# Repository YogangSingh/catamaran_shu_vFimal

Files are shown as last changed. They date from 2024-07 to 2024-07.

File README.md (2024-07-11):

# catamaran_shu_v2
 repo for the improved catamaran design

# Catamaran SHU

## Introduction
Catamaran SHU V2 is the improved version of the autonomous surface vehicle built and designed by me for my masters thesis. This version has improved electronics hardware and design changes that make the USV betters
## Features
- Feature 1: BNO055 IMU Integration.
- Feature 2: RTK GPS Added (GPS-RTK2 Board - ZED-F9P ).
- Feature 3: Dual mode control: radio control mode and autonomous mode.
- Feature 4: Arduino <-> ROS Integration on Arduino MEGA 2560..
- Feature 5: 360 Degree Lidar. (RPLidar s2)
  
## Getting Started
These instructions will get you a copy of the project up and running on your local machine for development and testing purposes.

### Prerequisites
What things you need to install the software and how to install them:
```
[Install ROS Noetic]
wget -c https://raw.githubusercontent.com/qboticslabs/ros_install_noetic/master/ros_install_noetic.sh && chmod +x ./ros_install_noetic.sh && ./ros_install_noetic.sh
``
[Install Ubuntu and Ubuntu Desktop on Raspberry Pi]
sudo apt-get update
sudo apt-get install ubuntu-desktop

```

### Installing
A step-by-step series of examples that tell you how to get a development environment running:

1. Clone the repo:
   ```
   git clone https://github.com/broskunta/catamaran_shu_v2.git
   ```
2. Navigate to the project directory:
   ```
   cd catamaran_shu_v2
   ```
3. Run catkin_make
   ```
   catkin_make
   ```
4. Navigate to the src directory:
   ```
   cd catamaran_shu_v2\src
   ```
5. Clone Required Repos
   ```
   git clone https://github.com/tu-darmstadt-ros-pkg/hector_slam
   git clone https://github.com/KumarRobotics/ublox.git
   git clone https://github.com/Slamtec/rplidar_ros
   git clone https://github.com/tilk/rtcm_msgs
   ```

## Usage
How to use the project:
```
1. Make sure the Arduino board with the IMU is connected on /dev/tty/USB0.
2. Make sure the GPS is connected on /dev/ttyACM0 on the RPi.
3. Make sure the Lidar is connected on /dev/ttyUSB1 on the RPi.
4. Run the robot with the usv_control.launch file
```

## Running the Tests
Explain how to run the automated tests for this system:
```
[For Straight Line Behaviour Test]
roslaunch gps_navigation straight_behaviour.launch
```
```
[For Circular Behaviour Test]
roslaunch gps_navigation circular_behaviour.launch 
```

## License
This project is licensed under the MIT License - see the [LICENSE.md](LICENSE.md) file for details.

## Acknowledgments
- Daniel Riley https://www.rctestflight.com/
- The team at Heron USV https://github.com/heron
- https://github.com/bsb808
- The team at TheConstruct. https://www.theconstructsim.com/
- The Technovation Team https://www.instructables.com/member/Technovation/
-  Sidney Okoroafor https://github.com/Syd-E

---

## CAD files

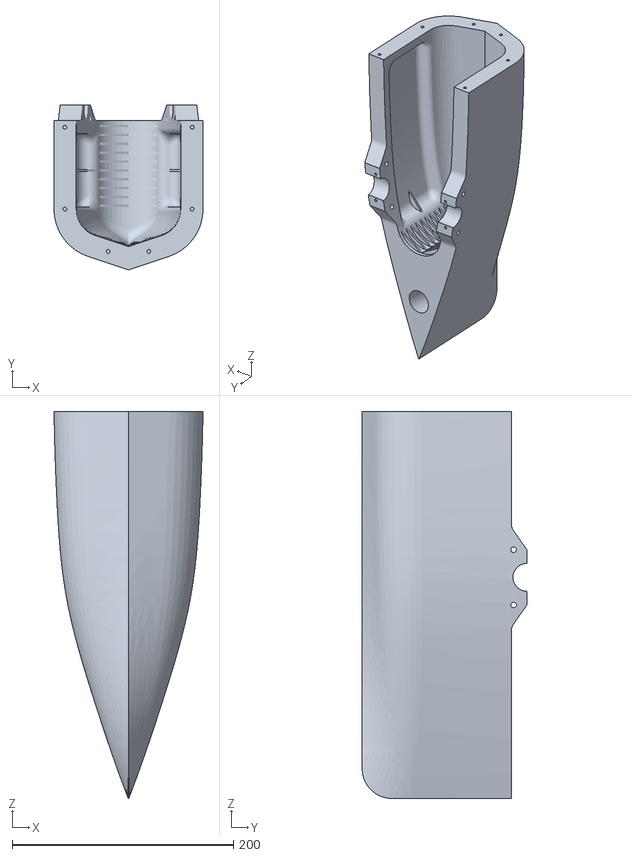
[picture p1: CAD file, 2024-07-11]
CAD Files/Cat Hull.STL
134.7 x 149.0 x 350.0

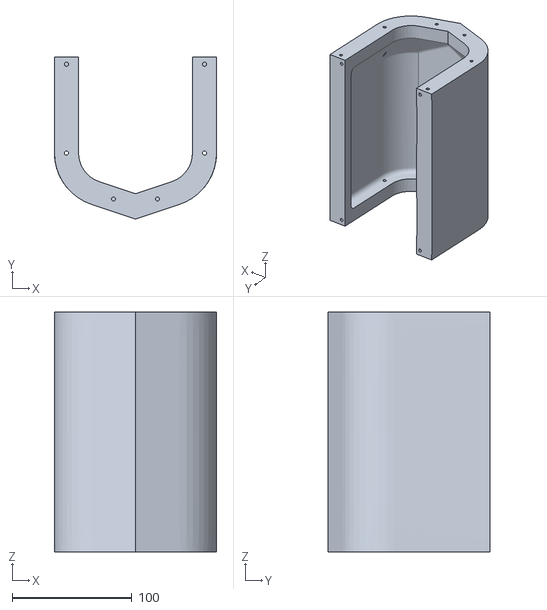
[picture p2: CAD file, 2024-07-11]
CAD Files/Cat Hull Middle.STL
135.3 x 135.0 x 200.0

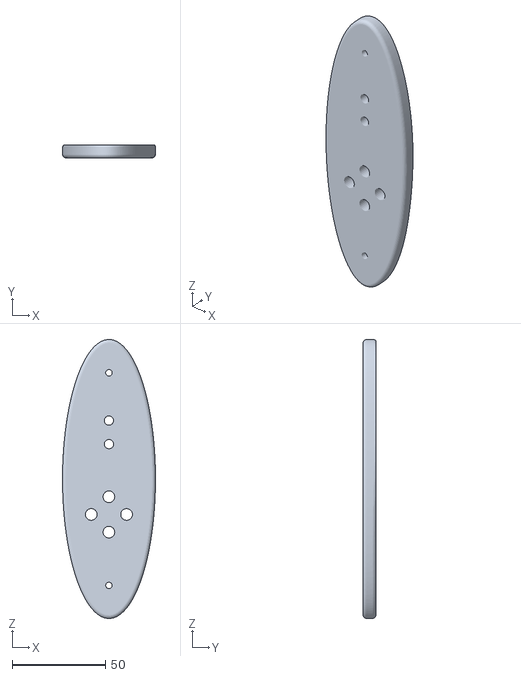
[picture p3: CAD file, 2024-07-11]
CAD Files/Mod-UW_base (Do not scale).stl
50.0 x 7.00 x 150.0

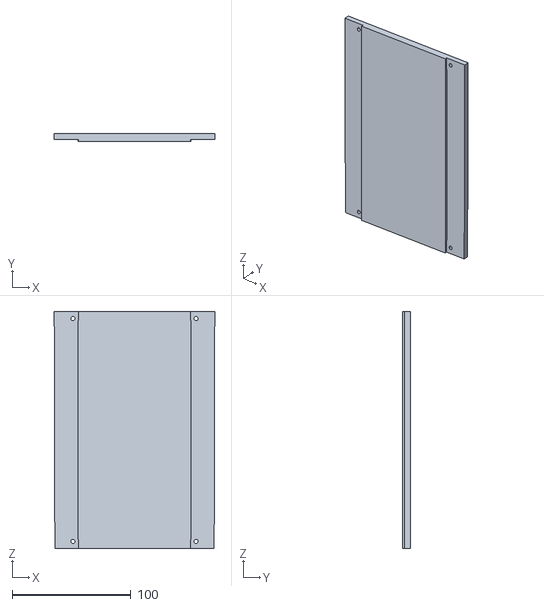
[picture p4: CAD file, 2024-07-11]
CAD Files/Boat middle cover.stl
135.5 x 7.00 x 200.0

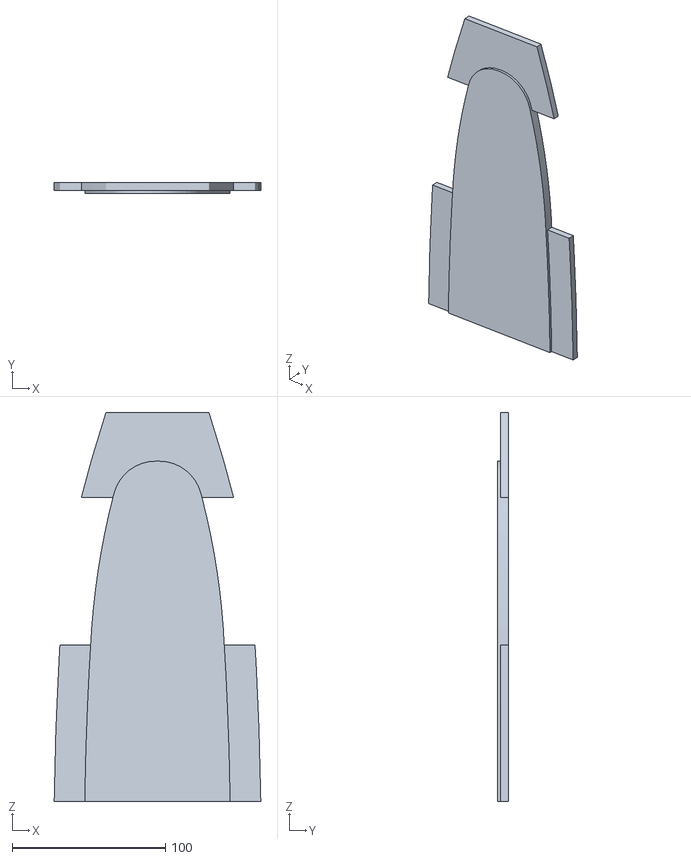
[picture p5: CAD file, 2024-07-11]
CAD Files/Boat cover 3.stl
134.7 x 7.00 x 253.5

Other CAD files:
CAD Files/Boat Front Cover.stl

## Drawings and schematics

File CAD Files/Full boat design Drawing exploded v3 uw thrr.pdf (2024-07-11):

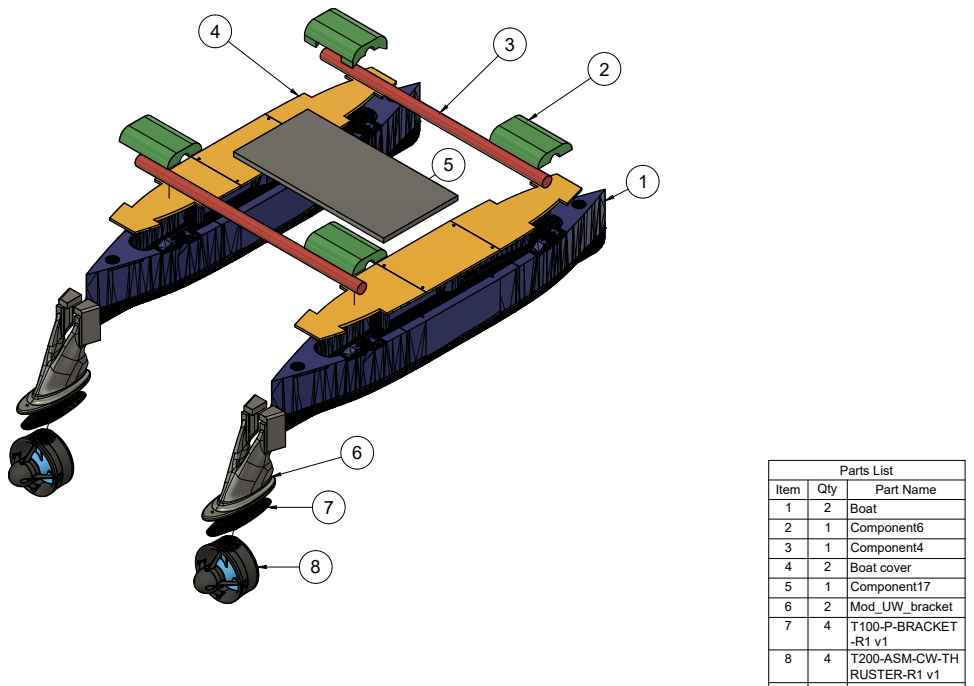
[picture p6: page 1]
Parts List; Item; Qty; Part Name 1; Boat 2; Component6 3; Component4 4; Boat cover 5; Component17 6; Mod_UW_bracket 7; T100-P-BRACKET; T200-ASM-CW-TH; RUSTER-R1 v1 9; Cat Hull v3

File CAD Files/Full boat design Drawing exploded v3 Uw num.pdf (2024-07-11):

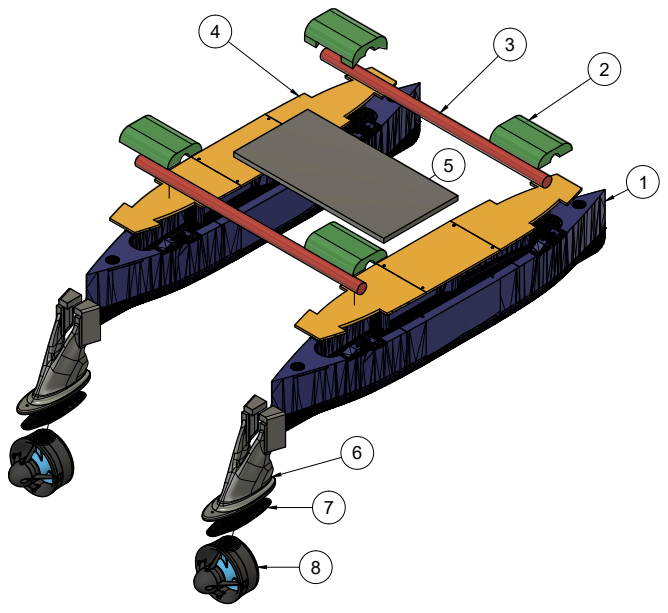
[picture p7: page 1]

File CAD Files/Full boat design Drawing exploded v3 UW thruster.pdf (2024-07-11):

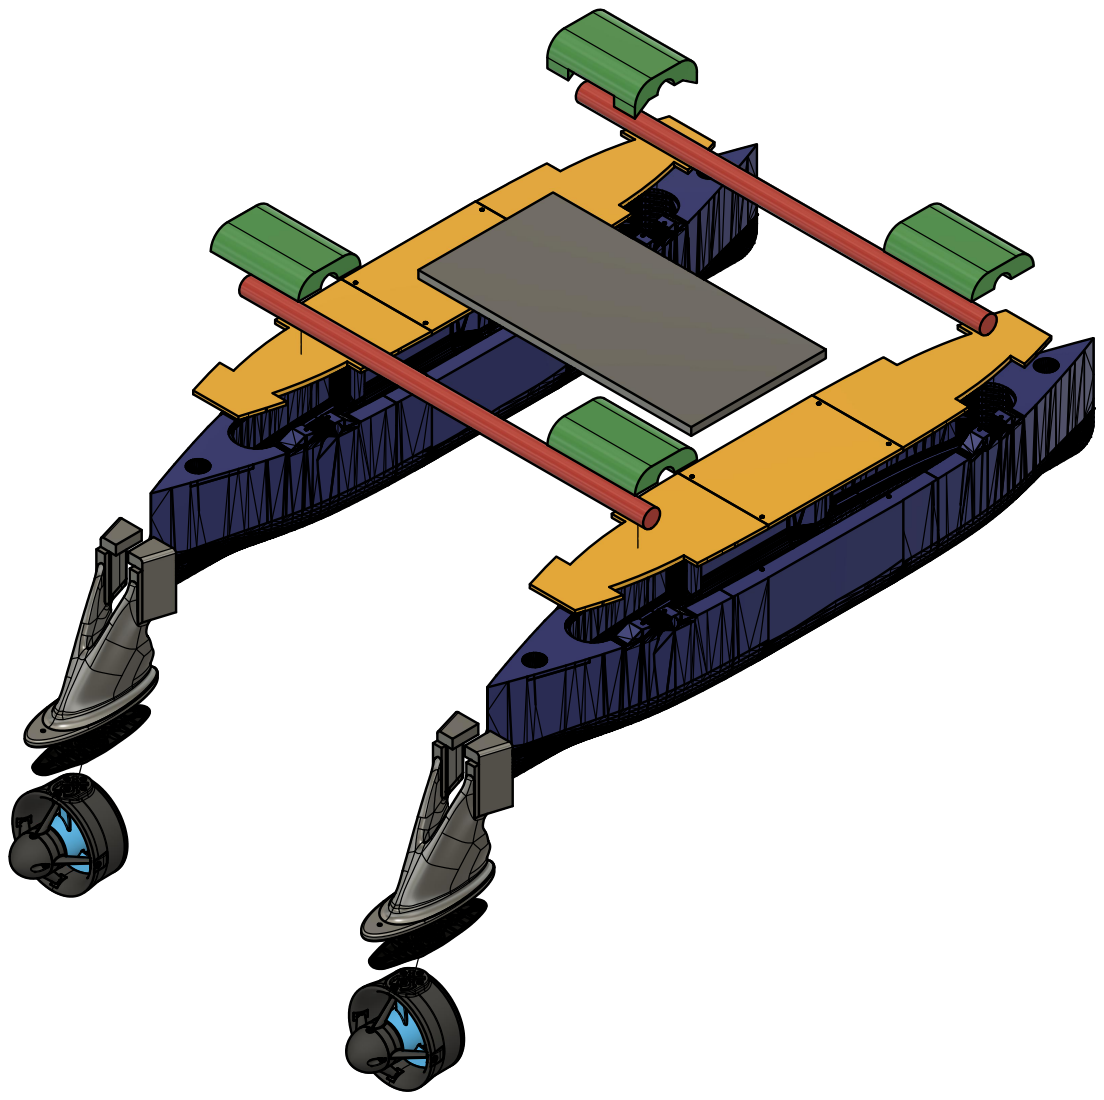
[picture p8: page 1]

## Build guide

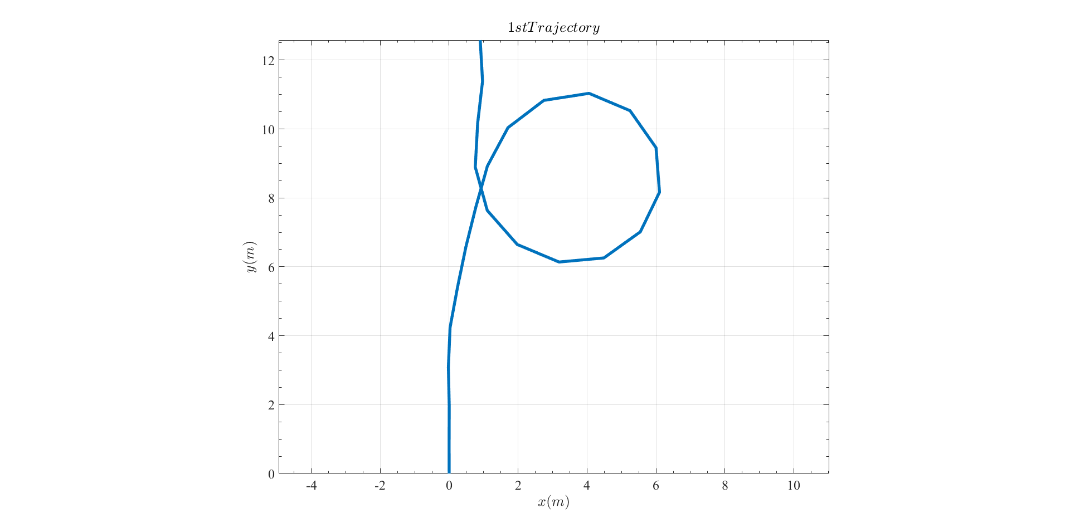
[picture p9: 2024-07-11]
USV2 Test Data/print1.png

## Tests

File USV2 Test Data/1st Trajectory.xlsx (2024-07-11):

X | Y | Xzero | Xpos | Yzero | .latitude | .longitude | /imu.orientation.w | /imu.orientation.x | /imu.orientation.y | /imu.orientation.z | elapsed time | receive time
599734.89 | 5911420.889 | 0 | 0 | 0 | 53.3413995 | -1.502048667 | 0.9506835938 | -0.02178955078 | -0.09460449219 | -0.2946166992 | 0.728779495 | 1716287602.731446062
599735.4683 | 5911420.308 | 0.5783463661 | -0.5783463661 | 0.5814168295 | 53.34139417 | -1.502040167 | 0.9490966797 | -0.02197265625 | -0.07751464844 | -0.3045043945 | 1.511456699 | 1716287603.514123266
599736.2732 | 5911419.508 | 1.383281925 | -1.383281925 | 1.38066116 | 53.34138683 | -1.502028333 | 0.9501342773 | -0.01995849609 | -0.07336425781 | -0.3024902344 | 2.288903725 | 1716287604.291570292
599737.0564 | 5911418.69 | 2.166414513 | -2.166414513 | 2.19891117 | 53.34137933 | -1.502016833 | 0.9447631836 | -0.02349853516 | -0.07092285156 | -0.319152832 | 3.068369249 | 1716287605.071035816
599737.9053 | 5911417.91 | 3.015346033 | -3.015346033 | 2.97868386 | 53.34137217 | -1.502004333 | 0.9591064453 | -0.00927734375 | -0.07989501953 | -0.271484375 | 3.848517702 | 1716287605.851184269
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

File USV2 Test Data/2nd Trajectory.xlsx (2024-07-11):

X | Y | Xzero | Yzero | .latitude | .longitude | /imu.orientation.w | /imu.orientation.x | /imu.orientation.y | /imu.orientation.z | elapsed time | receive time
599729.7333 | 5911415.346 | 0 | 0 | 53.3413506667 | -1.502127833 | 0.6889038086 | -0.05236816406 | -0.04803466797 | -0.7213745117 | 0.27339406 | 1716286998.273825933
599730.1028 | 5911415.725 | 0.3694890541 | 0.3787190001 | 53.3413540000 | -1.502122167 | 0.6795654297 | -0.0712890625 | -0.06744384766 | -0.7270507812 | 1.050185075 | 1716286999.050616948
599730.7109 | 5911416.368 | 0.977647335 | 1.02212236 | 53.3413596667 | -1.502112833 | 0.6727294922 | -0.06237792969 | -0.06005859375 | -0.7348022461 | 1.831201541 | 1716286999.831633414
599731.2326 | 5911416.899 | 1.499370209 | 1.552422171 | 53.3413643333 | -1.502104833 | 0.6684570312 | -0.03161621094 | -0.03106689453 | -0.7424316406 | 2.6101303 | 1716287000.610562173
599731.7215 | 5911417.41 | 1.988193605 | 2.06348349 | 53.3413688333 | -1.502097333 | 0.6654663086 | -0.04870605469 | -0.046875 | -0.743347168 | 3.39286495 | 1716287001.393296823
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

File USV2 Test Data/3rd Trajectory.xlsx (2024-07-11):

X | Y | Xpos | Ypos | Xzero | Yzero | .latitude | .longitude | /imu.orientation.w | /imu.orientation.x | /imu.orientation.y | /imu.orientation.z | elapsed time | receive time
599733.9305 | 5911421.648 | 0 | 0 | 0 | 0 | 53.3414065 | -1.502062833 | 0.866027832 | -0.03125 | -0.06274414062 | -0.4950561523 | 0.155708607 | 1716287119.157944043
599734.526 | 5911422.365 | -0.5955051631 | -0.7173321405 | 0.5955051631 | 0.7173321405 | 53.34141283 | -1.502053667 | 0.8772583008 | -0.02655029297 | -0.06121826172 | -0.4753417969 | 0.9399582740000001 | 1716287119.942193710
599735.0763 | 5911423.119 | -1.145847949 | -1.47081379 | 1.145847949 | 1.47081379 | 53.3414195 | -1.502045167 | 0.884765625 | -0.02655029297 | -0.06457519531 | -0.4607543945 | 1.71588904 | 1716287120.718124476
599735.6691 | 5911423.966 | -1.738630181 | -2.31792788 | 1.738630181 | 2.31792788 | 53.341427 | -1.502036 | 0.885925293 | -0.02709960938 | -0.06402587891 | -0.4585571289 | 2.495964736 | 1716287121.498200172
599736.3059 | 5911424.832 | -2.375407565 | -3.18451339 | 2.375407565 | 3.18451339 | 53.34143467 | -1.502026167 | 0.8879394531 | -0.02990722656 | -0.07354736328 | -0.4530639648 | 3.276257084 | 1716287122.278492520
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

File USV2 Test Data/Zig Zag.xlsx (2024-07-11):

X | Y | Xpos | Ypos | Xzero | Yzero | .latitude | .longitude | /imu.orientation.w | /imu.orientation.x | /imu.orientation.y | /imu.orientation.z | elapsed time | receive time
599744.1458 | 5911419.414 | 0 | 0 | 0 | 0 | 53.3413845 | -1.501910167 | 0.9755249023 | -0.02001953125 | -0.08563232422 | -0.2015380859 | 0.063026459 | 1716287800.064211793
599744.5885 | 5911418.422 | -0.442655905 | 0.9923276799 | 0.442655905 | -0.9923276799 | 53.3413755 | -1.501903833 | 0.9337768555 | -0.04223632812 | -0.08905029297 | -0.3439331055 | 0.8399374 | 1716287800.841122734
599744.657 | 5911417.273 | -0.511156555 | 2.14089241 | 0.511156555 | -2.14089241 | 53.34136517 | -1.501903167 | 0.8807983398 | -0.05523681641 | -0.07745361328 | -0.4638061523 | 1.621337312 | 1716287801.622522646
599744.37 | 5911416.136 | -0.224193134 | 3.27836629 | 0.224193134 | -3.27836629 | 53.341355 | -1.501907833 | 0.8164672852 | -0.06213378906 | -0.06872558594 | -0.5699462891 | 2.39909612 | 1716287802.400281454
599743.7474 | 5911415.121 | 0.398376218 | 4.293042149 | -0.398376218 | -4.293042149 | 53.341346 | -1.5019175 | 0.742980957 | -0.06994628906 | -0.06622314453 | -0.6622924805 | 3.18188167 | 1716287803.183067004
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

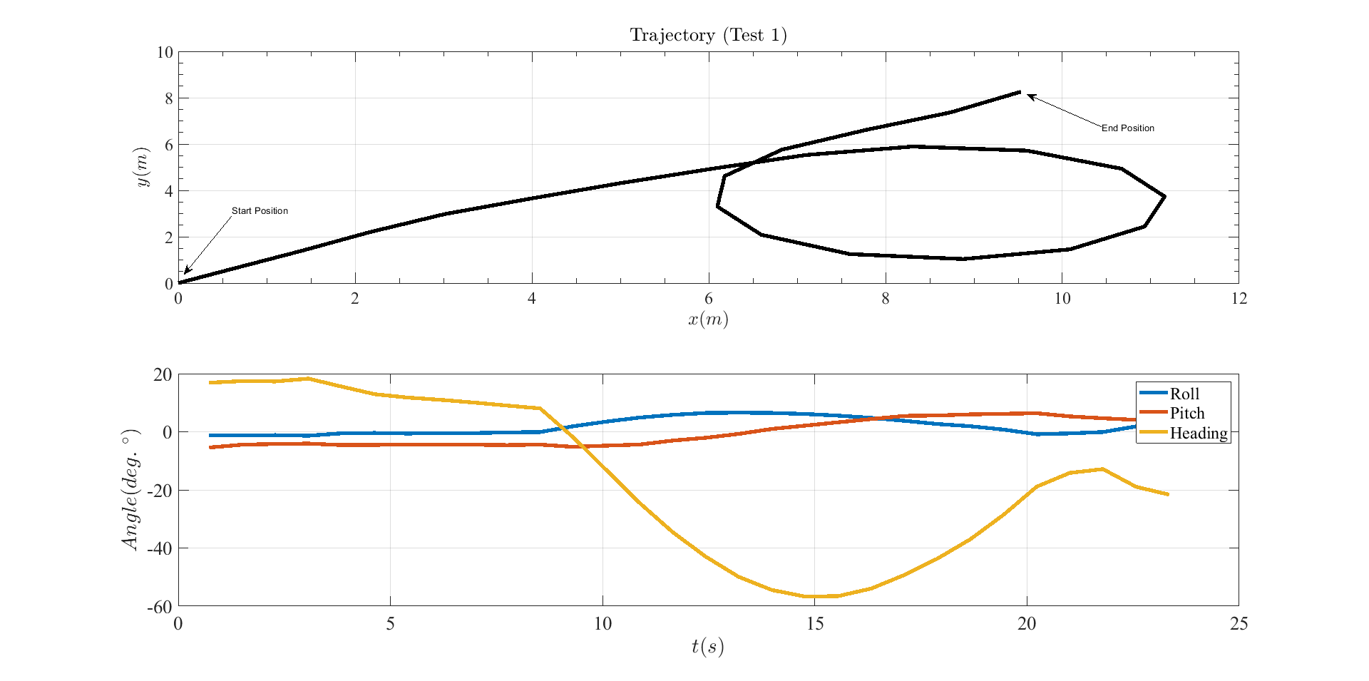
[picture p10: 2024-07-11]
USV2 Test Data/Test 1.png

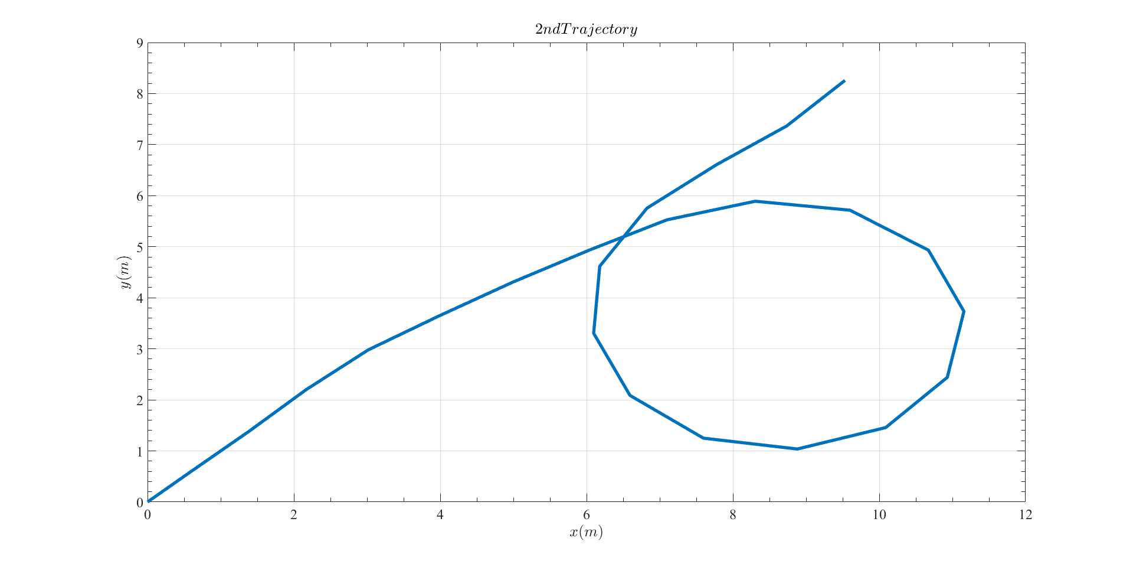
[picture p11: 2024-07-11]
USV2 Test Data/untitled.png

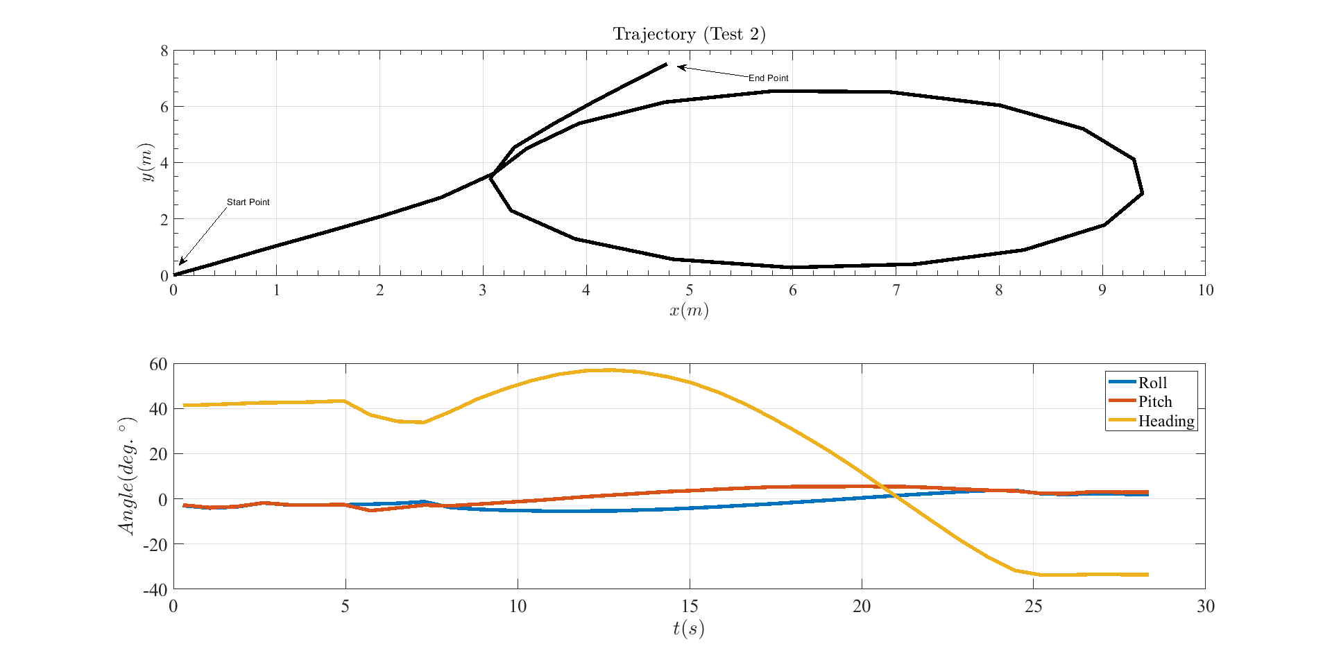
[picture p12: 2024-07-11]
USV2 Test Data/Test 22.png

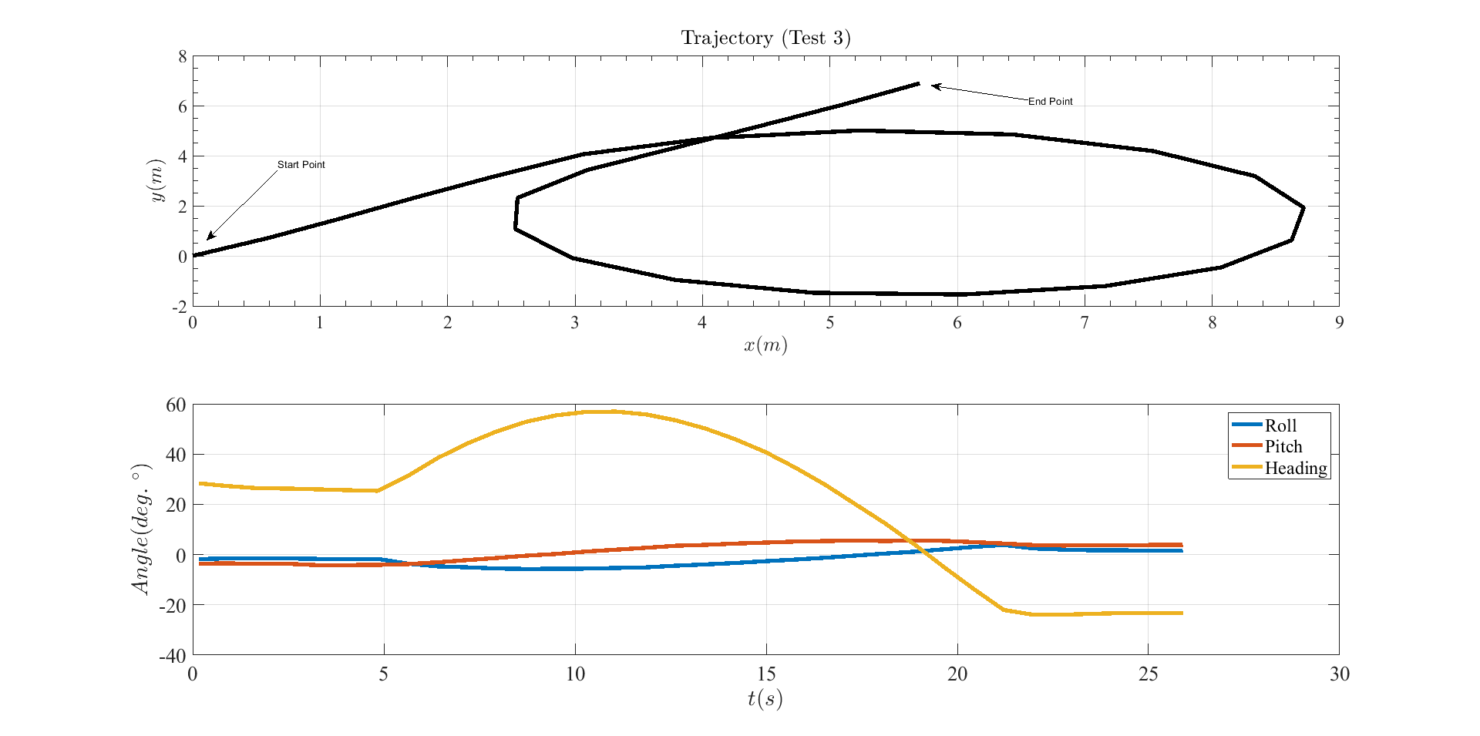
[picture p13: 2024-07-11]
USV2 Test Data/untitled13port.png

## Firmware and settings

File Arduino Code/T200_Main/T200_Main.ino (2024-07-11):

//IMU Code to send IMY data to the IMu part to ROS
//I will need angular velocity, linear acceleration,
//Orientation in quat from the IMU sensor to make this
//code work

//Working code is from ros-robot-programming-book-by turtlebot3-Developers

//ROS Libraries
#include <ros.h>
#include <nav_msgs/Path.h>
#include <sensor_msgs/Imu.h>
#include <tf/tf.h>
#include <tf/transform_broadcaster.h>
#include <geometry_msgs/Twist.h>

//include libraries for Transmitter
#include <SPI.h>
#include <Servo.h>
#include <IBusBM.h>
/*
 *    Connections
   =======================
   IMU
   =======================
   Connect SCL to SCL pin (analog 5 on Arduino UNO)
   Connect SDA to SDA pin (analog 4 on Arduino UNO)
   Connect VDD to 3-5V DC (depending on your board's logic level)
   Connect GROUND to common ground

  =======================
   GPS
  =======================


  =======================
   TRANSMITTER
  =======================


  =======================
   ESCs
  =======================

  =======================
   BOARD RADIO COMMS
  =======================
 * 
 */

// Other arduino libraries
#include <Wire.h>
#include <Adafruit_Sensor.h>
#include <Adafruit_BNO055.h>
#include <utility/imumaths.h>

//Start ROS Handle
ros::NodeHandle nh;

const int MAX_PATH_SIZE = 10;

sensor_msgs::Imu imu_msg;

ros::Publisher imu_pub("imu", &imu_msg);

geometry_msgs::TransformStamped tfs_msg;
tf::TransformBroadcaster tfbroadcaster;

/* Set the delay between fresh samples */
#define BNO055_SAMPLERATE_DELAY_MS (100)

/* Define BNO055 Object */
Adafruit_BNO055 bno = Adafruit_BNO055(55, 0x28, &Wire);

//define comms pins for transmitter
#define RUDDER_PIN 5
#define THROTTLE_PIN 6
#define MODE_PIN 7

//define ESCs pin
Servo left_esc; //left motor
Servo right_esc; //right motor

int left_motor_speed = 1500;
int right_motor_speed = 1500;

// // Read the number of a given channel and convert to the range provided.
// // If the channel is off, return the default value
int readChannel(int channelInput, int minLimit, int maxLimit, int defaultValue){
  int ch = pulseIn(channelInput, HIGH, 30000);
  if (ch < 100) return defaultValue;
  return map(ch, 1000, 2000, minLimit, maxLimit);
}

// Red the channel and return a boolean value
bool redSwitch(byte channelInput, bool defaultValue){
  int intDefaultValue = (defaultValue)? 100: 0;
  int ch = readChannel(channelInput, 0, 100, intDefaultValue);
  return (ch > 50);
}

// Callback functions for the path topics
void generatedPathCallback(const nav_msgs::Path& msg) {
    // Process and print data for /straight_line_behavior_generated_path
    Serial.println("Generated Path Data:");
    for (int i = 0; i < MAX_PATH_SIZE; ++i) {
        // Assuming a pose of all zeros is not valid and indicates the end of the array
        if (msg.poses[i].pose.position.x != 0 || msg.poses[i].pose.position.y != 0 || msg.poses[i].pose.position.z != 0) {
            Serial.print(msg.poses[i].pose.position.x);
            Serial.print(",");
            Serial.print(msg.poses[i].pose.position.y);
            Serial.print(",");
            Serial.print(msg.poses[i].pose.position.z);
            Serial.print("\n");
        } else {
            // Break the loop if the pose is not valid
            break;
        }
    }
}

void followedPathCallback(const nav_msgs::Path& msg) {
    // Process and print data for /straight_line_behavior_followed_path
    Serial.println("Followed Path Data:");
    for (int i = 0; i < MAX_PATH_SIZE; ++i) {
        if (msg.poses[i].pose.position.x != 0 || msg.poses[i].pose.position.y != 0 || msg.poses[i].pose.position.z != 0) {
            Serial.print(msg.poses[i].pose.position.x);
            Serial.print(",");
            Serial.print(msg.poses[i].pose.position.y);
            Serial.print(",");
            Serial.print(msg.poses[i].pose.position.z);
            Serial.print("\n");
        } else {
            break;
        }
    }
}



//wheel data
float wheel_radius = 0.1015; // meters
float wheel_separation = 0.31; // meters
int micros_min = 1500; // Min microseconds for ESC
int micros_max = 2000; // Max microseconds for ESC

//variables for autospeed command
int left_motor_speed_auto, right_motor_speed_auto;

// 25% of max RPM at 11.1V for 850KV motor
float max_rpm_at_25_percent = 850 * 11.1 * 0.25; // 25% of Maximum RPM

// Function to map RPM to microseconds
int mapRpmToMicroseconds(float rpm) {
    // Mapping from -max_rpm_at_25_percent to max_rpm_at_25_percent to micros_min to micros_max
    int micros = map(rpm, -max_rpm_at_25_percent, max_rpm_at_25_percent, micros_min, micros_max);
    return constrain(micros, micros_min, micros_max);
}

//Velocity callback function
void cmdVelCallback(const geometry_msgs::Twist& msg) {
    float linear_velocity = msg.linear.x; // Linear velocity in m/s
    float angular_velocity = msg.angular.z; // Angular velocity in rad/s

    // Calculate wheel linear velocities
    float v_left = linear_velocity - (angular_velocity * wheel_separation / 2);
    float v_right = linear_velocity + (angular_velocity * wheel_separation / 2);

    // Convert linear velocities to angular velocities (rad/s)
    float omega_left = v_left / wheel_radius;
    float omega_right = v_right / wheel_radius;

    // Convert angular velocities to RPM
    float rpm_left = (omega_left * 60) / (2 * PI);
    float rpm_right = (omega_right * 60) / (2 * PI);

    // Map RPM to microseconds
    left_motor_speed_auto = mapRpmToMicroseconds(rpm_left);
    right_motor_speed_auto = mapRpmToMicroseconds(rpm_right);
}
//define subscriber to cmd_vel to get angular and linear velocities
ros::Subscriber<geometry_msgs::Twist> sub("cmd_vel", cmdVelCallback);


//define subscribers
ros::Subscriber<nav_msgs::Path> subGeneratedPath("/straight_line_behavior_generated_path", generatedPathCallback);
ros::Subscriber<nav_msgs::Path> subFollowedPath("/straight_line_behavior_followed_path", followedPathCallback);

// define channel values from the transmitter
int ch1_value, ch3_value;
bool ch6_value;

static uint32_t pre_time;

//Setup
void setup() {

  // begin serial window
  Serial.begin(115200);

  //begin ROS parts
  nh.initNode();
  nh.advertise(imu_pub);
  nh.subscribe(sub);
  nh.subscribe(subGeneratedPath);
  nh.subscribe(subFollowedPath);
  tfbroadcaster.init(nh);
  Wire.begin();
  bno.begin();
  delay(1000);

    //define pins
  pinMode(RUDDER_PIN, INPUT);
  pinMode(THROTTLE_PIN, INPUT);
  pinMode(MODE_PIN, INPUT);

  Serial.println("[INFO]\tArming Motors");

  
    //attach ESCs
  left_esc.attach(31);
  right_esc.attach(13);

  left_esc.writeMicroseconds(left_motor_speed);
  right_esc.writeMicroseconds(right_motor_speed);
  delay(2000);
  Serial.println("[INFO]\tMotors are armed");
}

void loop()
{
  

  //start imu
  start_imu();
  
  nh.spinOnce();
  delay(BNO055_SAMPLERATE_DELAY_MS);

    get_control_data();
  
  bool mode = get_mode();
  if (mode == 0) //manual mode
    {
      //get throttle and rudder values
      int throttle = get_throttle();
      int rudder = get_rudder();

      //write values to esc
      left_motor_speed = left_speed_manual(throttle, rudder);
      right_motor_speed = right_speed_manual(throttle,rudder);

      left_esc.writeMicroseconds(left_motor_speed);
      right_esc.writeMicroseconds(right_motor_speed);
    }
  else
  {
    //auto mode
    //read speed values of Vx and Vz from ROS publisher cmd_vel
    // then translate it to speed for each esc.
    
    //stop motors
    left_motor_speed = 1500;
    right_motor_speed = 1500;

    //get speed from the publisher
    //inear_// reads linear and angular velocity
    //get speed from the publisher
    //inear_// reads linear and angular velocity
    left_esc.writeMicroseconds(left_motor_speed_auto);
    right_esc.writeMicroseconds(right_motor_speed_auto);
    //convert speeds to 
    //write speeds to the motors
   

  }

  Serial.print("Left Motor Speed: ");
  Serial.println(left_motor_speed);
  Serial.print(" Right Motor Speed: ");
  Serial.println(right_motor_speed);

  nh.spinOnce(); // Handle ROS callbacks
      
}

void start_imu()
{
  
    //get readings from IMU
  imu::Quaternion quat = bno.getQuat(); //quarternion
  imu::Vector<3> gyroData = bno.getVector(Adafruit_BNO055::VECTOR_GYROSCOPE); //angular velocity
  imu::Vector<3> accData = bno.getVector(Adafruit_BNO055::VECTOR_LINEARACCEL);  // Get acceleration data


  if (millis() - pre_time >= 50)
  {
  pre_time = millis();  
  
  imu_msg.header.stamp = nh.now();
  imu_msg.header.frame_id = "imu_link";
  
  //print out the data going to the message.
  //quat messages
  imu_msg.angular_velocity.x = gyroData.x();
  imu_msg.angular_velocity.y = gyroData.y();
  imu_msg.angular_velocity.z = gyroData.z();
  imu_msg.angular_velocity_covariance[0] = 0.02;
  imu_msg.angular_velocity_covariance[1] = 0;
  imu_msg.angular_velocity_covariance[2] = 0;
  imu_msg.angular_velocity_covariance[3] = 0;
  imu_msg.angular_velocity_covariance[4] = 0.02;
  imu_msg.angular_velocity_covariance[5] = 0;
  imu_msg.angular_velocity_covariance[6] = 0;
  imu_msg.angular_velocity_covariance[7] = 0;
  imu_msg.angular_velocity_covariance[8] = 0.02;

  //linear accelaration
  imu_msg.linear_acceleration.x = accData.x();
  imu_msg.linear_acceleration.y= accData.y();
  imu_msg.linear_acceleration.z = accData.z();
  imu_msg.linear_acceleration_covariance[0] = 0.04;
  imu_msg.linear_acceleration_covariance[1] = 0;
  imu_msg.linear_acceleration_covariance[2] = 0;
  imu_msg.linear_acceleration_covariance[3] = 0;
  imu_msg.linear_acceleration_covariance[4] = 0.04;
  imu_msg.linear_acceleration_covariance[5] = 0;
  imu_msg.linear_acceleration_covariance[6] = 0;
  imu_msg.linear_acceleration_covariance[7] = 0;
  imu_msg.linear_acceleration_covariance[8] = 0.04;

  //Linear orientation
  imu_msg.orientation.w = quat.w();
  imu_msg.orientation.x = quat.x();
  imu_msg.orientation.y = quat.y();
  imu_msg.orientation.z = quat.z();

  imu_msg.orientation_covariance[0] = 0.0025;
  imu_msg.orientation_covariance[1] = 0;
  imu_msg.orientation_covariance[2] = 0;
  imu_msg.orientation_covariance[3] = 0;
  imu_msg.orientation_covariance[4] = 0.0025;
  imu_msg.orientation_covariance[5] = 0;
  imu_msg.orientation_covariance[6] = 0;
  imu_msg.orientation_covariance[7] = 0;
  imu_msg.orientation_covariance[8] = 0.0025;

  //publish the messages
  imu_pub.publish(&imu_msg);

  tfs_msg.header.stamp = nh.now();
  tfs_msg.header.frame_id = "base_link";
  tfs_msg.child_frame_id = "imu_link";
  tfs_msg.transform.rotation.w = quat.w();
  tfs_msg.transform.rotation.x = quat.x();
  tfs_msg.transform.rotation.y = quat.y();
  tfs_msg.transform.rotation.z = quat.z();

  tfs_msg.transform.translation.x = 0.0;
  tfs_msg.transform.translation.y = 0.0;
  tfs_msg.transform.translation.z = 0.0;

  tfbroadcaster.sendTransform(tfs_msg);
  }

}

void get_control_data()
{
  ch1_value = pulseIn(RUDDER_PIN, HIGH);
  ch3_value = pulseIn(THROTTLE_PIN, HIGH);
  ch6_value = redSwitch(MODE_PIN, false);

  Serial.print("Rudder: ");
  Serial.print(ch1_value);
  Serial.print(" Throttle: ");
  Serial.print(ch3_value);
  Serial.print(" Mode: ");
  Serial.print(ch6_value);
  Serial.print(" Left Motor Speed: ");
  Serial.print(left_motor_speed);
  Serial.print( "Right Motor Speed: ");
  Serial.print(right_motor_speed);
  delay(500);
}

bool get_mode()
{
  ch6_value = redSwitch(MODE_PIN, false);
  return ch6_value;
}

int get_throttle()
{
  return pulseIn(THROTTLE_PIN, HIGH);
}

int get_rudder()
{
   return pulseIn(RUDDER_PIN, HIGH);
}

int left_speed_manual(int throttle, int rudder) {
    // Calculate the difference from the neutral rudder position (1500)
    int rudder_offset = rudder - 1500;

    // Increase speed on the left motor when rudder moves to the right (positive offset)
    int speed = throttle + (rudder_offset / 2); // Divide to reduce effect

    // Ensure the speed does not exceed 2000 RPM or drop below 1500 RPM
    return constrain(speed, 1500, 2000);
}

int right_speed_manual(int throttle, int rudder) {
    // Calculate the difference from the neutral rudder position (1500)
    int rudder_offset = rudder - 1500;

    // Decrease speed on the right motor when rudder moves to the right (positive offset)
    int speed = throttle - (rudder_offset / 2); // Divide to reduce effect

    // Ensure the speed does not exceed 2000 RPM or drop below 1500 RPM
    return constrain(speed, 1500, 2000);
}

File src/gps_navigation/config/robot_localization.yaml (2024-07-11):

# Configuration for robot odometry EKF

frequency: 20
sensor_timeout: 0.1
two_d_mode: true
transform_time_offset: 0.0
transform_timeout: 0.0
use_control: false
publish_tf: true

## Currently using the Heron Default Configuration

# Complete the frames section
odom_frame: odom
base_link_frame: base_link
world_frame: odom
map_frame: map

# GPS Odometry (from Navsat Transform)
odom0: odometry/gps  # topic name from the transform node
odom0_config: [true, true, false,
               false, false, false,
               false, false, false,
               false, false, false,
               false, false, false]
odom0_queue_size: 10
odom0_nodelay: false
odom0_differential: false
odom0_relative: false
odom0_pose_rejection_threshold: 5
odom0_twist_rejection_threshold: 1

# External IMU
imu0_config: [false, false, false,
              true,  true,  false,
              false, false, false,
              true,  true,  true,
              true,  true,  true]
imu0_nodelay: false
imu0_differential: false
imu0_relative: true
imu0_queue_size: 5
imu0_pose_rejection_threshold: 0.8                 # Note the difference in parameter names
imu0_twist_rejection_threshold: 0.8                #
imu0_linear_acceleration_rejection_threshold: 0.8  

# GPS Velocity
# twist0: navsat/vel_cov
# twist0_config: [false,  false,  false,
#                 false, false, false,
#                 true, true, false,
#                 false, false, false,
#                 false, false, false]
# twist0_queue_size: 10
# twist0_nodelay: true
# twist0_differential: false
# twist0_relative: false

# [ADVANCED] Some IMUs automatically remove acceleration due to gravity, and others don't. If yours doesn't, please set
# this to true, and *make sure* your data conforms to REP-103, specifically, that the data is in ENU frame.
imu0_remove_gravitational_acceleration: true

# [ADVANCED]  The EKF and UKF models follow a standard predict/correct cycle. During prediction, if there is no
# acceleration reference, the velocity at time t+1 is simply predicted to be the same as the velocity at time t. During
# correction, this predicted value is fused with the measured value to produce the new velocity estimate. This can be
# problematic, as the final velocity will effectively be a weighted average of the old velocity and the new one. When
# this velocity is the integrated into a new pose, the result can be sluggish covergence. This effect is especially
# noticeable with LIDAR data during rotations. To get around it, users can try inflating the process_noise_covariance
# for the velocity variable in question, or decrease the  variance of the variable in question in the measurement
# itself. In addition, users can also take advantage of the control command being issued to the robot at the time we
# make the prediction. If control is used, it will get converted into an acceleration term, which will be used during
# predicition. Note that if an acceleration measurement for the variable in question is available from one of the
# inputs, the control term will be ignored.
# Whether or not we use the control input during predicition. Defaults to false.
use_control: true
# Whether the input (assumed to be cmd_vel) is a geometry_msgs/Twist or geometry_msgs/TwistStamped message. Defaults to
# false.
stamped_control: false
# The last issued control command will be used in prediction for this period. Defaults to 0.2.
control_timeout: 0.2
# Which velocities are being controlled. Order is vx, vy, vz, vroll, vpitch, vyaw.
control_config: [true, false, false, false, false, true]
# Places limits on how large the acceleration term will be. Should match your robot's kinematics.
acceleration_limits: [1.3, 0.0, 0.0, 0.0, 0.0, 3.4]
# Acceleration and deceleration limits are not always the same for robots.
deceleration_limits: [1.3, 0.0, 0.0, 0.0, 0.0, 4.5]
# If your robot cannot instantaneously reach its acceleration limit, the permitted change can be controlled with these
# gains
acceleration_gains: [0.8, 0.0, 0.0, 0.0, 0.0, 0.9]
# If your robot cannot instantaneously reach its deceleration limit, the permitted change can be controlled with these
# gains
deceleration_gains: [1.0, 0.0, 0.0, 0.0, 0.0, 1.0]
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

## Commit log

2024-07-11 updated files
    [Boat Front Cover.stl, Boat cover 3.stl, Boat middle cover.stl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]
2024-07-11 folder for test data and results added
    [1st Trajectory.xlsx, 2nd Trajectory.xlsx, 3rd Trajectory.xlsx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]
